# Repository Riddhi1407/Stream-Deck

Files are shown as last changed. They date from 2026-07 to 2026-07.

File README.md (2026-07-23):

# Stream-Deck
***
Assembly

This is a Multifunction Programmable deck with 8 keys programmable graphical keypad, a 4.3 inch multifunctional tft lcd screen with touch and 2 programmable rotary knobs with switches. It has user customizable haptic feedback, that can be customized on the deviceitself. The deck has Bluetooth and Wi-Fi connectivity options and can be used wirelessly tocontrol connected peripherals. It also has a Lithium-Polymer battery with Type-C charging forwireless use that provides a battery life of 10 hour.

**Features:**
-8 keys Programmable Graphical Keypad
-4.3 inch TFT LCD Multifunction Screen with Capacitive Touch
-2 Rotary knobs with switches
-Haptic Feedback
-Bluetooth 5.3 and Wi-Fi
-Type-C Charging
-10 Hour Battery Life

### Keypad  
The 8 key graphical keypad can show the graphics on the keys. Keys of the keypad becustomized using the onboard tft lcd to show diferent graphics. The functions of the keyscan also be set or changed using the deck itself or other device. Keypad customizations canbe saved as modes and can be reused as presets.

### Display
The 4.3 inch tft lcd display with capacitive touch is used for controlling the functions of thedeck and also for controlling the connected peripherals. The screen can also be used astrackpad by turning off the backlight and/or numpad by selecting these options on the deckitself.

### Knobs 
Similar to the keypad, the rotary knobs and their switches can also be customized using theonboard lcd display. The primary function to control the lcd interface, however it can bechanged for doing any task.

### Haptics
The deck has haptic feedback feature for key presses, touch interactions with the displayand for the rotary knobs and their switches. The haptic feedback function can be customizedfor key presses, touch interactions and rotary knobs or it can also be completely turned ofusing the screen.

### Wireless
The deck has Bluetooth 5.3 and Wi-Fi wireless connectivity options to control the connectedperipherals and the deck using other device. The deck van also br connected through USBType-C for controlling the connected peripherals or device and it can also be used to controlor program the deck.

### Power
The deck has a 10000 mAh Lithium-Polymer battery that can power the device for 10 hour inwireless mode and not connected to power. It can be charged by USB Type-C. The deck canalso be powered by USB Type-C.

### Schematic
**Main Schematic**
Main Schematic

**Keypad Top Layer Schematic**
Keypad Top Layer Schematic

**Keypad Bottom Layer Schematic**
Keypad Bottom Layer Schematic

### PCB Layout  
PCB Layout

### PCB 3D CAD
**PCB Front**
PCB Front

**PCB Back**
PCB Back

### CASE 3D CAD

**Assembly**
Assembly

**Assembly Top**
Assembly Top

**Case Top**
Case Front

**Case Bottom**
Case Bottom

**Display 1** 
Display 1

**Display 2**
Display 2

**Keycap** 
Keycap

**Rubber Membrane**
Rubber Sheet

**Spacer**
Spacer Sheet

**Knob**
Knob Cap

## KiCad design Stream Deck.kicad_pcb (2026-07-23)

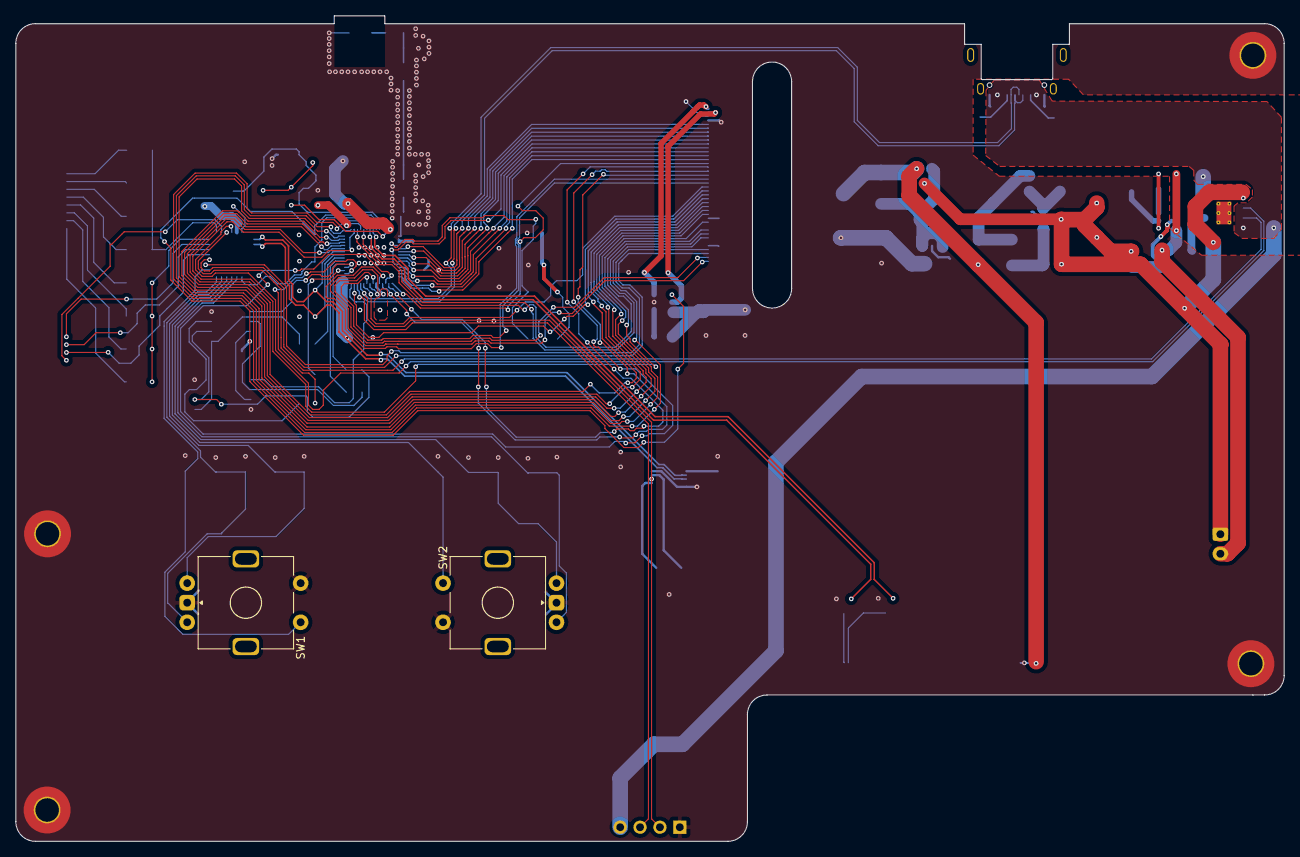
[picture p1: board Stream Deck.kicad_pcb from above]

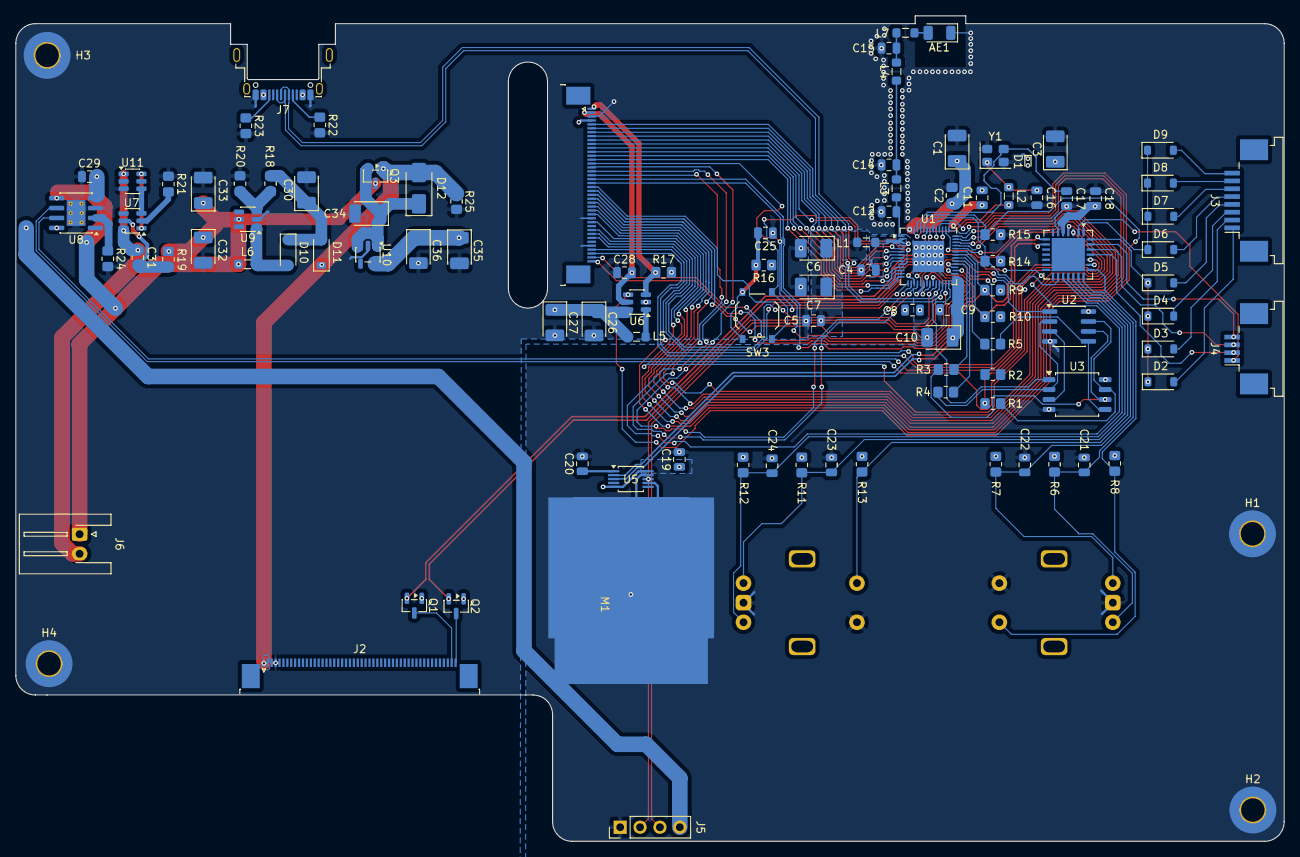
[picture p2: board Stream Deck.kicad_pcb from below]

Board: 4 copper layers, 162.1 x 105.5 mm, 110 parts (108 on the bottom side), 109 nets.

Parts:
AE1: Antenna_Chip; Johanson_2450AT18x100_2400-2500Mhz
C1, C3, C6, C7, C32, C34, C35: 10uF; CP_EIA-3528-21_Kemet-B_HandSolder
C2: 10nF; C_0805_2012Metric_Pad1.18x1.45mm_HandSolder
C4, C5, C8, C9, C11, C18, C19, C20, C21, C22, C23, C24, C25: 0.1uF; C_0805_2012Metric
C10, C26, C27, C36: 1uF; CP_EIA-3528-21_Kemet-B_HandSolder
C12, C14, C15: C; C_0805_2012Metric
C16, C17: 24pF; C_0805_2012Metric
C28: 220nF; C_0805_2012Metric
C29, C31: 100nF; C_0805_2012Metric
C30, C33: 22uF; CP_EIA-3528-21_Kemet-B_HandSolder
D1: ESD9B3.3ST5G; D_SOD-923
D2, D3, D4, D5, D6, D7, D8, D9: D; D_SOD-123
D10, D11: 1N5822; D_SOD-123
D12: SS34; D_SMA
H1, H2, H3, H4: MountingHole_Pad; MountingHole_3mm_Pad_TopBottom
J1: Conn_01x40_MountingPin; TE_4-1734839-0_1x40-1MP_P0.5mm_Horizontal
J2: Conn_01x50_MountingPin; TE_5-1734839-0_1x50-1MP_P0.5mm_Horizontal
J3: Conn_01x08_MountingPin; TE_84952-8_1x08-1MP_P1.0mm_Horizontal
J4: Conn_01x04_MountingPin; TE_84952-4_1x04-1MP_P1.0mm_Horizontal
J5: Conn_01x04_Pin; PinHeader_1x04_P2.54mm_Vertical
J6: Conn_01x02_Pin; JST_XH_S2B-XH-A-1_1x02_P2.50mm_Horizontal
J7: USB_C_Receptacle_USB2.0_16P; USB_C_Receptacle_Amphenol_12401948E412A
L1: 2nH; L_0805_2012Metric_Pad1.05x1.20mm_HandSolder
L2: 24nH; L_0805_2012Metric_Pad1.05x1.20mm_HandSolder
L3, L4, L7: L; L_0805_2012Metric_Pad1.05x1.20mm_HandSolder
L5, L6: 22uH; L_0805_2012Metric_Pad1.05x1.20mm_HandSolder
M1: Motor_DC; PUI HD-EMB1104 Motor
Q1, Q2: BSS138; SOT-23
Q3: AO3401A; SOT-23
R1, R2, R3, R4, R5: 0; R_0805_2012Metric_Pad1.20x1.40mm_HandSolder
R6, R7, R8, R11, R12, R13, R14, R15, R16: 10K; R_0805_2012Metric_Pad1.20x1.40mm_HandSolder
R9, R10: 2.2K; R_0805_2012Metric_Pad1.20x1.40mm_HandSolder
R17: 2; R_0805_2012Metric_Pad1.20x1.40mm_HandSolder
R18: 7.5k; R_0805_2012Metric_Pad1.20x1.40mm_HandSolder
R19: 100; R_0805_2012Metric_Pad1.20x1.40mm_HandSolder
R20: 1k; R_0805_2012Metric_Pad1.20x1.40mm_HandSolder
R21: 1K; R_0805_2012Metric_Pad1.20x1.40mm_HandSolder
R22, R23: 5.1K; R_0805_2012Metric_Pad1.20x1.40mm_HandSolder
R24: 1.2k; R_0805_2012Metric_Pad1.20x1.40mm_HandSolder
R25: 100K; R_0805_2012Metric_Pad1.20x1.40mm_HandSolder
SW1, SW2: RotaryEncoder_Switch; ROT_Alps_EC11E-Switch
SW3: SW_Push; SW_Push_1P1T_XKB_TS-1187A
U1: ESP32-S3; QFN-56-1EP_7x7mm_P0.4mm_EP4x4mm
U2: ESP-PSRAM64H; SOIC-8_3.9x4.9mm_P1.27mm
U3: W25Q16JVSS; SOIC-8_5.3x5.3mm_P1.27mm
U4: MCP23017_ML; QFN-28-1EP_6x6mm_P0.65mm_EP4.25x4.25mm
U5: DRV2605LDGS; VSSOP-10_3x3mm_P0.5mm
U6: AP3019AKTTR; TSOT-23-6
U7: DW01A; SOT-23-6
U8: TP4056-42-ESOP8; SOIC-8-1EP_3.9x4.9mm_P1.27mm_EP2.41x3.3mm_ThermalVias
U9: SDB628; SOT-23-6
U10: AP2112K-3.3; SOT-23-5
U11: FS8205; SOT-23-6
Y1: YSX321SL 40MHz; Oscillator_SMD_Abracon_ASE-4Pin_3.2x2.5mm

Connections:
+3V3: C1.1, C2.1, C3.1, C5.1, C6.1, C7.1, C8.1, C9.1, C10.1, C11.1, C18.1, C19.1, C26.1, C27.1, C35.1, C36.1, D1.2 (A2), J1.4, L1.2, L5.1, Q1.1 (G), Q2.1 (G), R6.1, R7.1, R8.1, R9.1, R10.1, R11.1, R12.1, R13.1, R14.1, R16.1, U1.20 (VDD3P3_RTC), U1.29 (VDD_SPI), U1.46 (VDD3P3_CPU), U1.55 (VDDA), U1.56 (VDDA), U2.8 (VCC), U3.8 (VCC), U4.5 (VDD), U5.5 (EN), U5.10 (VDD), U6.6 (V_{IN}), U10.5 (VOUT)
+5V: D11.1 (K), D12.2 (A), J2.1, J2.2, Q3.1 (G), R25.1
/A: C28.1, J1.2, U6.5 (V_{OUT})
/B0: J1.21, U1.24 (GPIO18)
/B1: J1.22, U1.27 (GPIO21)
/B2: J1.23, U1.38 (GPIO33)
/B3: J1.24, U1.39 (GPIO34)
/B4: J1.25, U1.40 (GPIO35)
/B5: J1.26, U1.41 (GPIO36)
/B6: J1.27, U1.42 (GPIO37)
/B7: J1.28, U1.43 (GPIO38)
/B+: C32.1, C33.1, J6.1, L6.1, Q3.3 (D), R19.2, U8.5 (BAT), U9.5 (IN)
/B-: C31.2, J6.2, U7.6 (VSS), U11.1 (S1)
/CHRG: U4.3 (GPB6), U8.7 (~CHRG)
/CLK: J1.30, U1.44 (MTCK)
/COL0: J4.1, U4.2 (GPB5)
/COL1: J4.2, U4.25 (GPB0)
/COL2: J4.3, U4.26 (GPB1)
/COL3: J4.4, U4.27 (GPB2)
/CS0: U1.32 (SPICS0), U2.1 (~CE)
/CS1: U1.28 (SPICS1), U3.1 (~CS)
/CS2: J1.38, U4.24 (GPA7)
/CTRL: R15.1, U1.52 (GPIO46), U6.4 (CTRL)
/D+: J5.2, J7.A6 (D+), J7.B6 (D+), U1.26 (GPIO20/USB_D+)
/D-: J5.3, J7.A7 (D-), J7.B7 (D-), U1.25 (GPIO19/USB_D-)
/DE: J1.34, U1.48 (MTMS)
/EC1A: C22.1, R7.2, SW1.A, U4.20 (GPA3)
/EC1B: C21.1, R6.2, SW1.B, U4.21 (GPA4)
/EC1S: R8.2, SW1.S1, U4.22 (GPA5)
/EC2A: C24.1, R12.2, SW2.A, U4.17 (GPA0)
/EC2B: C23.1, R11.2, SW2.B, U4.18 (GPA1)
/EC2S: R13.2, SW2.S1, U4.19 (GPA2)
/G0: J1.13, U1.13 (GPIO8)
/G1: J1.14, U1.14 (GPIO9)
/G2: J1.15, U1.15 (GPIO10)
/G3: J1.16, U1.16 (GPIO11)
/G4: J1.17, U1.17 (GPIO12)
/G5: J1.18, U1.18 (GPIO13)
/G6: J1.19, U1.19 (GPIO14)
/G7: J1.20, U1.23 (GPIO17)
/HS: J1.32, U1.45 (MTDO)
/INTA: R14.2, U1.51 (GPIO45), U4.16 (INTA)
/K: J1.1, R17.1, U6.3 (FB)
/OUT+: M1.+, U5.7 (OUT+)
/OUT-: M1.-, U5.9 (OUT-)
/R0: J1.5, U1.5 (GPIO0)
/R1: J1.6, U1.6 (GPIO1)
/R2: J1.7, U1.7 (GPIO2)
/R3: J1.8, U1.8 (GPIO3)
/R4: J1.9, U1.9 (GPIO4)
/R5: J1.10, U1.10 (GPIO5)
/R6: J1.11, U1.11 (GPIO6)
/R7: J1.12, U1.12 (GPIO7)
/ROW0: D2.1 (K), D3.1 (K), D4.1 (K), D5.1 (K), U4.28 (GPB3)
/ROW1: D6.1 (K), D7.1 (K), D8.1 (K), D9.1 (K), U4.1 (GPB4)
/RST: J1.37, U4.23 (GPA6)
/RXD: Q1.2 (S), U1.50 (U0RXD)
/SCL: R9.2, U1.37 (SPICLK_P), U4.8 (SCK), U5.2 (SCL)
/SCL0: J1.39, U1.21 (XTAL_32K_P)
/SCLK: R3.2, U2.6 (SCLK), U3.6 (CLK)
/SDA: R10.2, U1.36 (SPICLK_N), U4.9 (SDA), U5.3 (SDA)
/SDA0: J1.40, U1.22 (XTAL_32K_N)
/SI: R5.2, U2.5 (SI/SIO), U3.5 (DI/IO_{0})
/SIO2: U2.3 (SIO2), U3.3 (~WP/IO_{2})
/SIO3: R1.2, U2.7 (SIO3), U3.7 (~HOLD/~RESET/IO_{3})
/SO: R4.2, U2.2 (SO/SIO), U3.2 (DO/IO_{1})
/STDBY: U4.4 (GPB7), U8.6 (~STDBY)
/SW0: D2.2 (A), J3.1
/SW1: D3.2 (A), J3.2
/SW2: D4.2 (A), J3.3
/SW3: D5.2 (A), J3.4
/SW4: D6.2 (A), J3.5
/SW5: D7.2 (A), J3.6
/SW6: D8.2 (A), J3.7
/SW7: D9.2 (A), J3.8
/TXD: Q2.2 (S), U1.49 (U0TXD)
/VS: J1.33, U1.47 (MTDI)
GND: AE1.1 (FEED), C1.2, C2.2, C3.2, C4.2, C5.2, C6.2, C7.2, C8.2, C9.2, C10.2, C11.2, C12.1, C14.1, C15.2, C16.2, C17.2, C18.2, C19.2, C20.2, C21.2, C22.2, C23.2, C24.2, C25.2, C26.2, C27.2, C28.2, C29.2, C30.2, C32.2, C33.2, C34.2, C35.2, C36.2, D1.1 (A1), H1.1, H2.1, H3.1, H4.1, J1.3, J1.29, J1.36, J2.3, J2.4, J2.5, J5.4, J7.A1 (GND), J7.A12 (GND), J7.B1 (GND), J7.B12 (GND), M1.GND, R15.2, R17.2, R20.2, R21.1, R22.2, R23.2, R24.2, R25.2, SW1.C, SW1.S2, SW2.C, SW2.S2, U1.57 (GND), U2.4 (VSS), U3.4 (GND), U4.6 (VSS), U5.8 (GND), U6.2 (GND), U8.3 (GND), U8.9 (EPAD), U9.2 (GND), U10.2 (GND), U11.3 (S2), Y1.2 (GND), Y1.4 (GND)
unnamed: AE1.2 (PCB_Trace), L7.2
unnamed: C4.1, L1.1, U1.2 (VDD3P3), U1.3 (VDD3P3)
unnamed: C14.2, L3.2, L4.1
unnamed: C15.1, L4.2, L7.1
unnamed: C25.1, R16.2, SW3.2
unnamed: D10.2 (A), L6.2, U9.1 (SW)
unnamed: C30.1, D10.1 (K), D11.2 (A), R18.1
unnamed: C34.1, D12.1 (K), Q3.2 (S), U10.1 (VIN), U10.3 (EN)
unnamed: J2.49, Q1.3 (D)
unnamed: J2.50, Q2.3 (D)
unnamed: J7.A5 (CC1), R22.1
unnamed: J7.B5 (CC2), R23.1
unnamed: SW3.1, U1.4 (CHIP_PU)
unnamed: C12.2, L3.1, U1.1 (LNA_IN)
unnamed: R3.1, U1.33 (SPICLK)
unnamed: R5.1, U1.35 (SPID)
unnamed: R1.1, U1.30 (SPIHD)
unnamed: R4.1, U1.34 (SPIQ)
unnamed: R2.1, U1.31 (SPIWP)
unnamed: C17.1, U1.53 (XTAL_N), Y1.3 (XOUT)
unnamed: L2.2, U1.54 (XTAL_P)
unnamed: C20.1, U5.1 (REG)
unnamed: L5.2, U6.1 (SW)
unnamed: R21.2, U7.2 (CSI)
unnamed: C31.1, R19.1, U7.5 (VDD)
unnamed: R24.1, U8.2 (PROG)
unnamed: R18.2, R20.1, U9.3 (FB)
unnamed: U7.1 (OD), U11.6 (G1)
unnamed: U7.3 (OC), U11.4 (G2)
unnamed: C16.1, L2.1, Y1.1 (XIN)
VBUS: C29.1, J5.1, J7.A4 (VBUS), J7.A9 (VBUS), J7.B4 (VBUS), J7.B9 (VBUS), U8.4 (V_{CC}), U8.8 (CE)

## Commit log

2026-07-23 Enhance README with Stream-Deck features and specs
    Added detailed description of the Stream-Deck features, including specifications for the keypad, display, knobs, haptics, wireless connectivity, power, schematics, and CAD layouts.
2026-07-23 Update README with assembly component images
    Added images and descriptions for various assembly components.
2026-07-23 Revise details in README
    Updated battery life and specifications in the README.
